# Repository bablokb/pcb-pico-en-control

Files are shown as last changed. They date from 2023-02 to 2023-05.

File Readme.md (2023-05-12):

Pico EN Control
===============

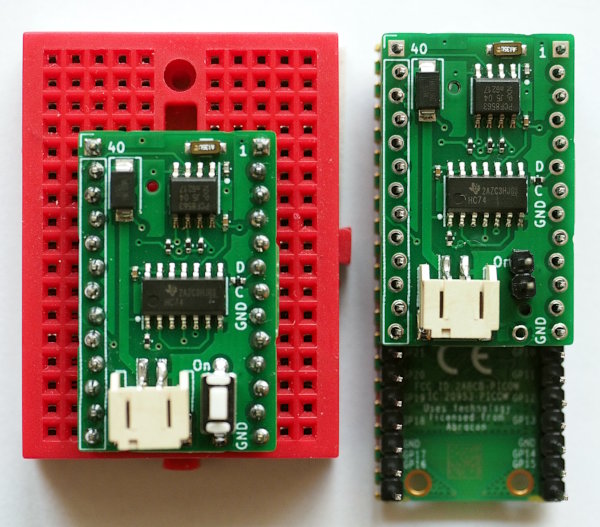
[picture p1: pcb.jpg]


This is a simple breakout to control the enable pin of a Pico to
minimize battery usage.

Functions:
  * Enable using a button, a RTC or an external signal
  * Disable by pulling a GPIO high from your program
  * keep time

The target application of this design is a program that runs in
intervals. After startup the program executes it's tasks, sets
the next wakup time and then pulls the "done"-GPIO high.
The circuitry then pulls the enable-pin low, thus limiting the
battery consumption to a very low level.

The design of the breakout allows it to be connected directly on the bottom
side of the pico. Note that the breakout uses a solderless layout for the
pins, i.e. it will hold by friction. But don't expect miracles, it may
or may not work depending on your pins. For production use, you should
definitely solder the breakout.

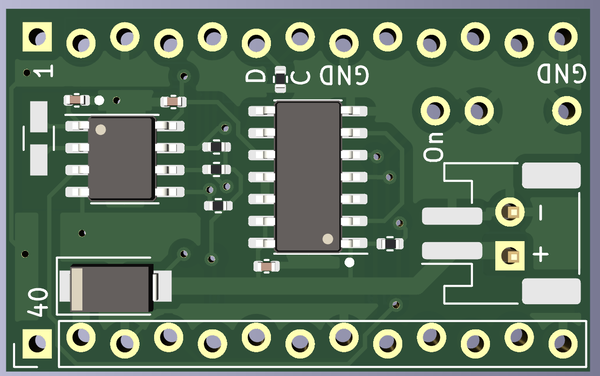
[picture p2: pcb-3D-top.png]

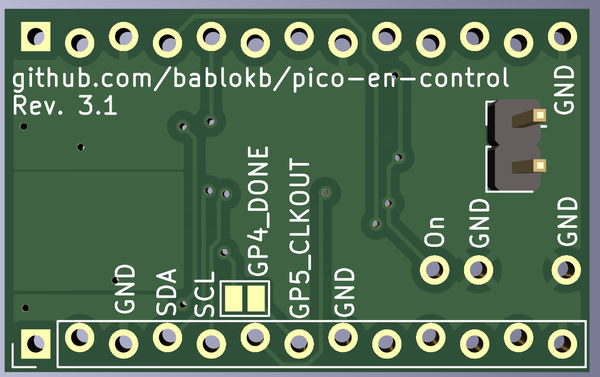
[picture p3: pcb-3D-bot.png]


Hardware Components
-------------------

A D-type flip-flop drives the enable pin of the Pico. A
button, the RTC or an external signal will reset the flip-flop,
which pulls the enable pin high.

The "done"-pin of the Pico is connected to the CLK-pin of
the flip-flop. A rising edge will toggle the enable pin.

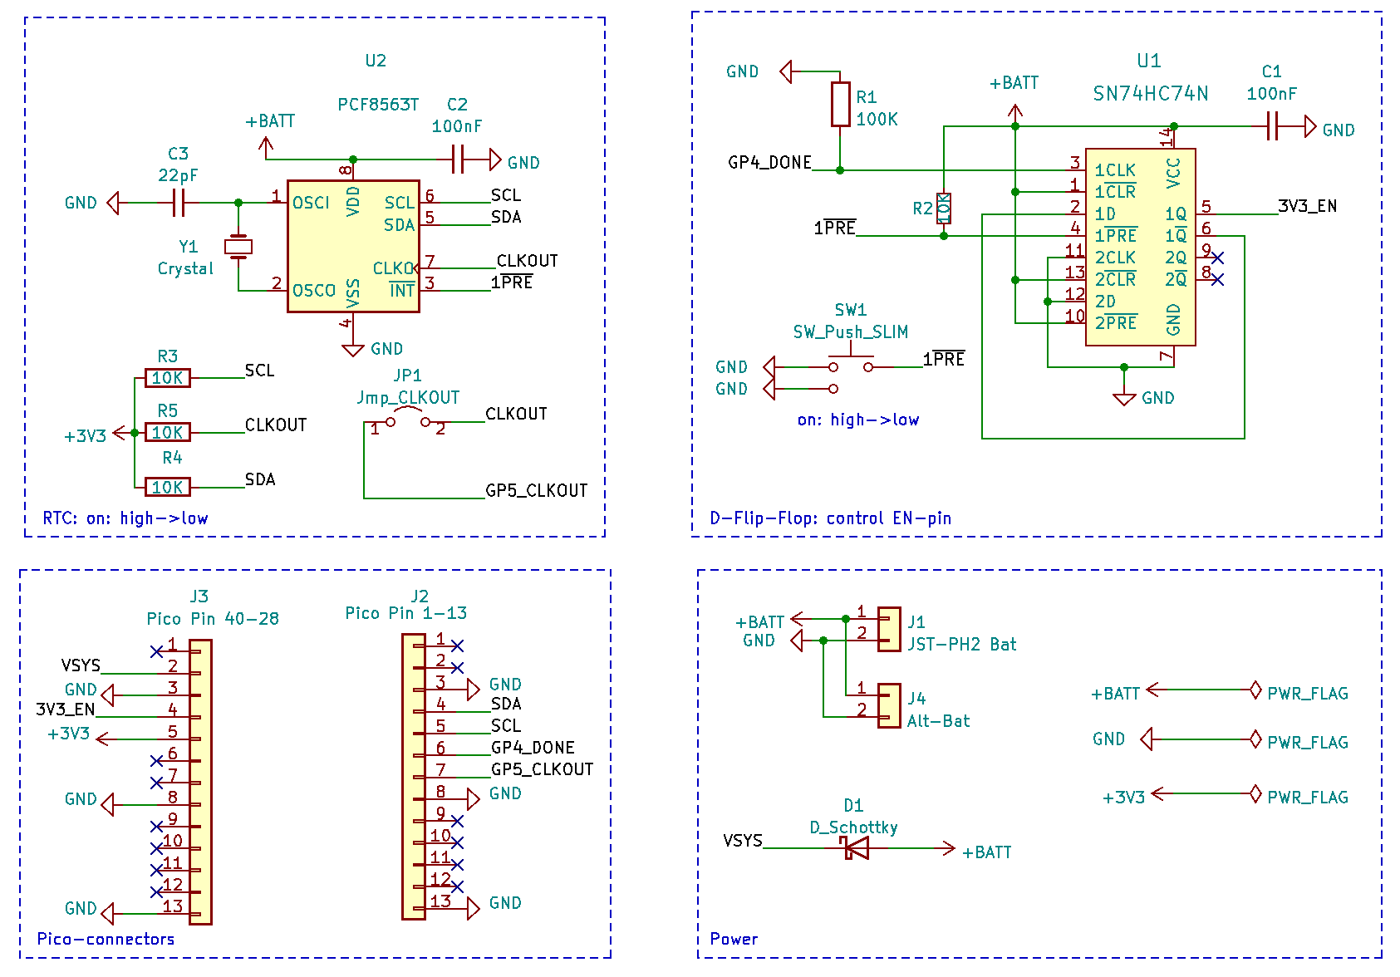
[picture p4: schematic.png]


PCB
---

PCB design files are in `pico-en-control.kicad`.

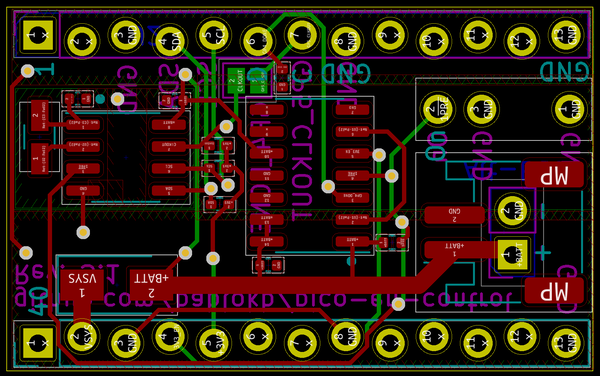
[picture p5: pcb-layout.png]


Ready to use production files for JLCPCB are in `production_files`.

Software
--------

A simple example program implemented in CircuitPython
is provided in `src/main.py`. The software provides some boilerplate
code for timer and alarm-based wake up.

In timer-mode, the program uses the countdown-timer of the rtc. It
blinks the on-board LED for ten seconds, then goes to sleep for 15 seconds.

Measured current:

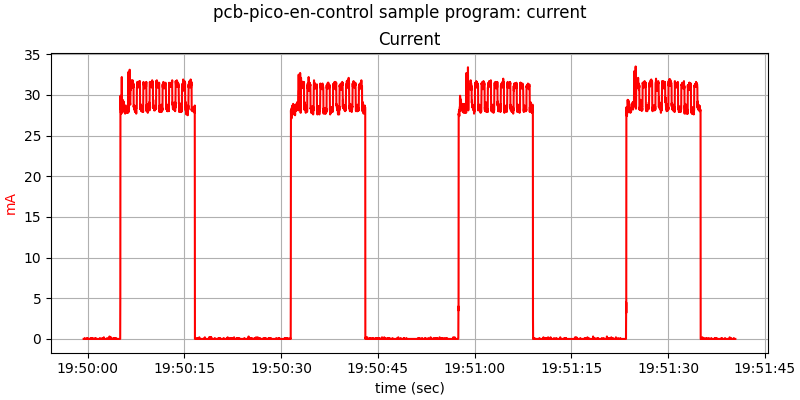
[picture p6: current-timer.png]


For longer intervals alarm-based wake up is more suitable. Since the rtc
does not support seconds for alarms, it will always fire on "full minutes".
The current measurement demonstrates this behavior (the first off-interval
is shorter than the following off-intervals):

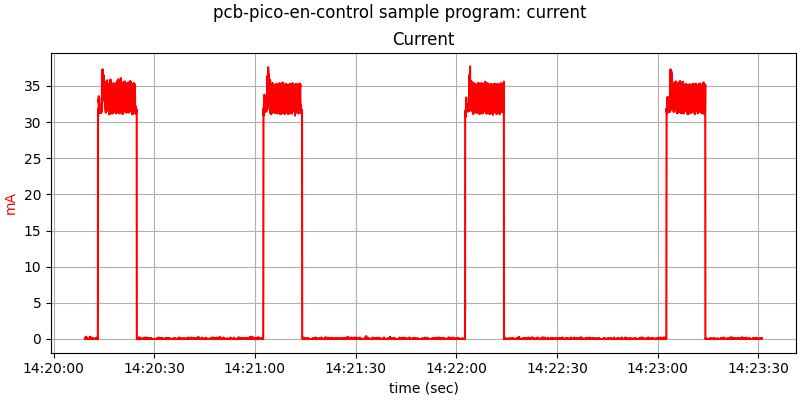
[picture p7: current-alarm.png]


Current in off-state is about 75µA (with CLKOUT disabled):

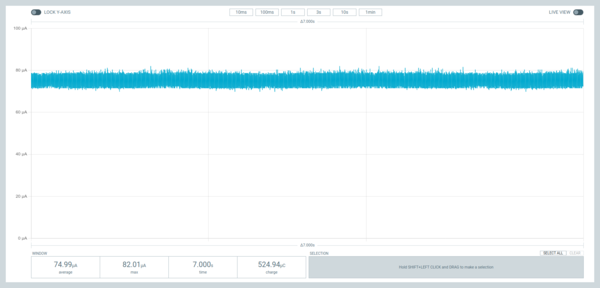
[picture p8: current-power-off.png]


License
-------

[![CC BY-SA 4.0][cc-by-sa-shield]][cc-by-sa]

This work is licensed under a
[Creative Commons Attribution-ShareAlike 4.0 International
License][cc-by-sa].

[][cc-by-sa]

[cc-by-sa]: http://creativecommons.org/licenses/by-sa/4.0/
[cc-by-sa-image]: https://licensebuttons.net/l/by-sa/4.0/88x31.png
[cc-by-sa-shield]:
https://img.shields.io/badge/License-CC%20BY--SA%204.0-lightgrey.svg

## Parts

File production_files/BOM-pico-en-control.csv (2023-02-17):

Comment | Designator | Footprint | LCSC
100nF | C1,C2 | C_0402_1005Metric | C1525
22pF | C3 | C_0402_1005Metric | C1555
D_Schottky | D1 | D_SMA | C2480
100K | R1 | R_0402_1005Metric | C25741
10K | R2,R3,R4,R5 | R_0402_1005Metric | C25744
Crystal | Y1 | Crystal_SMD_3215-2Pin_3.2x1.5mm | C32346
SN74HC74N | U1 | SOIC-14_3.9x8.7mm_P1.27mm | C6762
PCF8563T | U2 | SOIC-8_3.9x4.9mm_P1.27mm | C7440
Jmp_CLKOUT | JP1 | SolderJumper-2_P1.3mm_Open_Pad1.0x1.5mm

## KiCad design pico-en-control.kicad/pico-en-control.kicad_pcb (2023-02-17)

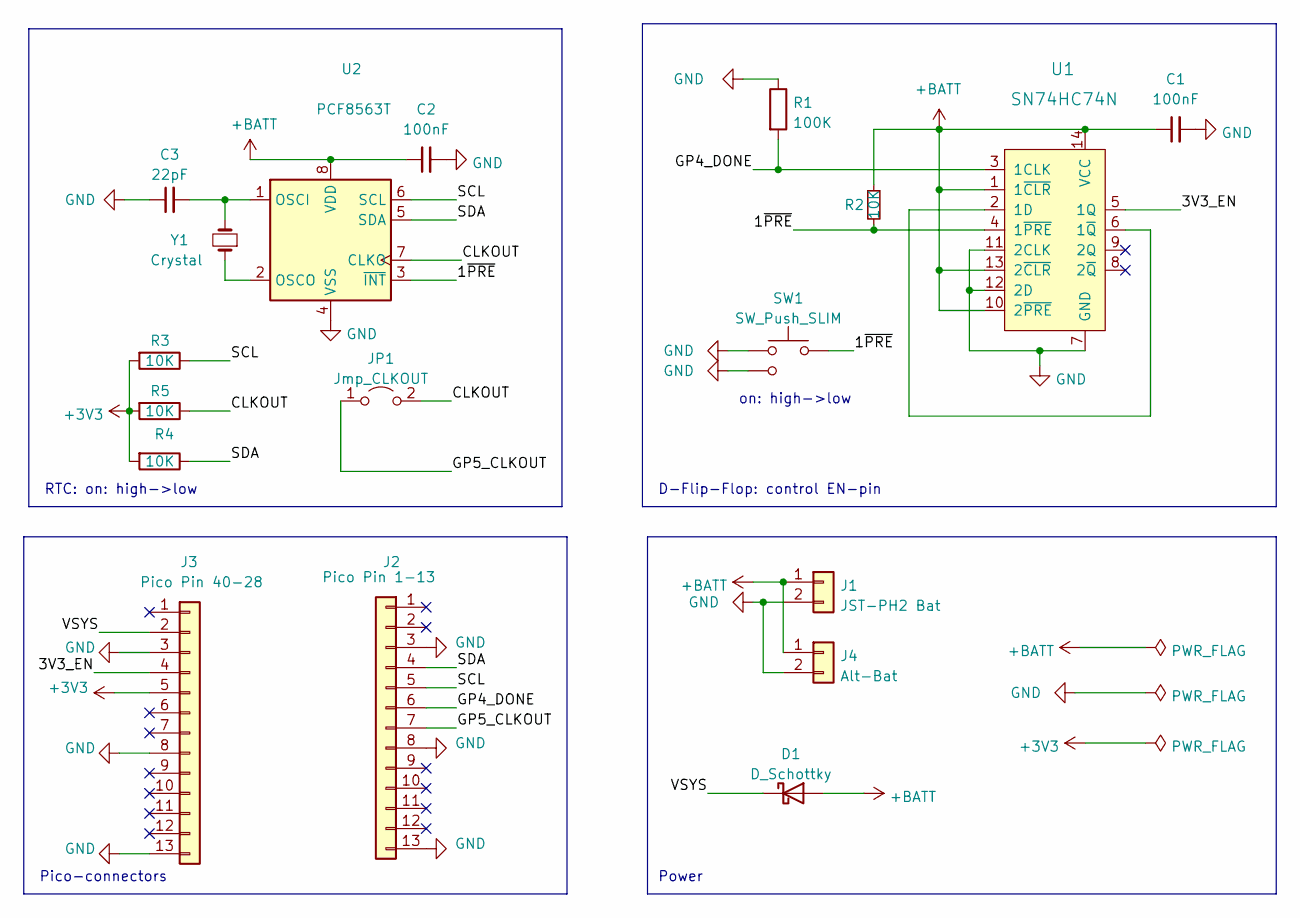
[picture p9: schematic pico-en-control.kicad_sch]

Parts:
C1, C2: 100nF; C_0402_1005Metric; LCSC C1525
C3: 22pF; C_0402_1005Metric; LCSC C1555
D1: D_Schottky; D_SMA; LCSC C2480
J1: JST-PH2 Bat; JST_PH_S2B-PH-SM4-TB_1x02-1MP_P2.00mm_Horizontal
J2: Pico Pin 1-13; Connector_1x13_no_solder
J3: Pico Pin 40-28; Connector_1x13_no_solder
J4: Alt-Bat; PinHeader_1x02_P2.54mm_Vertical
JP1: Jmp_CLKOUT; SolderJumper-2_P1.3mm_Open_Pad1.0x1.5mm
R1: 100K; R_0402_1005Metric; LCSC C25741
R2, R3, R4, R5: 10K; R_0402_1005Metric; LCSC C25744
SW1: SW_Push_SLIM; SW_PUSH_SLIM_1x4
U1: SN74HC74N; SOIC-14_3.9x8.7mm_P1.27mm; MPN SN74HC74N; Digi-Key_PN 296-1602-5-ND
U2: PCF8563T; SOIC-8_3.9x4.9mm_P1.27mm; LCSC C7440
Y1: Crystal; Crystal_SMD_3215-2Pin_3.2x1.5mm; LCSC C32346

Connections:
+3V3: J3.5, R3.2, R4.2, R5.2
+BATT: C1.1, C2.1, D1.2 (A), J1.1, J4.1, R2.1, U1.1 (1~CLR), U1.10 (2~PRE), U1.13 (2~CLR), U1.14 (VCC), U2.8 (VDD)
/1~PRE: R2.2, SW1.2, U1.4 (1~PRE), U2.3 (~INT)
/3V3_EN: J3.4, U1.5 (1Q)
/CLKOUT: JP1.2 (B), R5.1, U2.7 (CLKO)
/GP4_DONE: J2.6, R1.2, U1.3 (1CLK)
/GP5_CLKOUT: J2.7, JP1.1 (A)
/SCL: J2.5, R3.1, U2.6 (SCL)
/SDA: J2.4, R4.1, U2.5 (SDA)
/VSYS: D1.1 (K), J3.2
GND: C1.2, C2.2, C3.1, J1.2, J2.3, J2.8, J2.13, J3.3, J3.8, J3.13, J4.2, R1.1, SW1.1, SW1.3 (1), U1.7 (GND), U1.11 (2CLK), U1.12 (2D), U2.4 (VSS)
unnamed: C3.2, U2.1 (OSCI), Y1.2
unnamed: U1.2 (1D), U1.6 (1~Q)
unnamed: U2.2 (OSCO), Y1.1

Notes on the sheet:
Power
D-Flip-Flop: control EN-pin
Pico-connectors
RTC: on: high->low
on: high->low

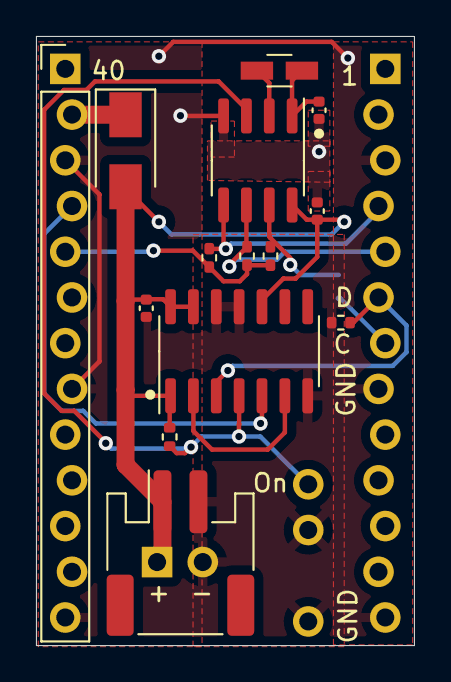
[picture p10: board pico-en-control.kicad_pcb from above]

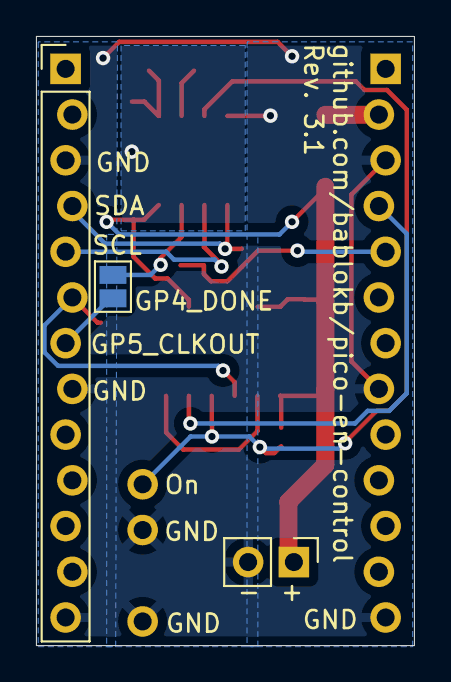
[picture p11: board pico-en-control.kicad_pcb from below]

Board: 2 copper layers, 21.0 x 33.8 mm, 18 parts (3 on the bottom side), 14 nets.

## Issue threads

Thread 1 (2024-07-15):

Can you please add a version for esp32-wroom-32?

mosheliv, 2024-07-15:
They are just much cheaper and for any practical purpose just as good for sensors.

bablokb, 2024-07-15:
The ESP32-WROOM-32 is an old chip not recommended for newer designs. And "much" cheaper is something I would not agree with. The chip itself is much cheaper, but the difference in dev-board prices is not that high. Especially if you don't buy the cheapest stuff you can find on Ali.

BTW: you can use the existing PCB with any 3V3 MCU. You cannot just plug it into the device.

mosheliv, 2024-07-15:
I am trying to use this to have a sensor monitoring soil moisture of a
plant once a day. As I'm thinking about 10+ sensors, the difference between
the cheap esp32 and the pico is substantial. Yes, i did realize i could use
it independently (and will, already ordered a few from jlbpcb, thank you
for making it so easy) but no harm in asking...
Cheap Esp32 is about 2.5$, pico wifi is about 10$.
Best regards and many thanks for the work you did!

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

bablokb, 2024-07-15:
Yes, no problem. Designing it for a specific ESP32 breakout would not be much work, but I would have to know the exact pinout, have a sample dev-board and so on. But I am busy with other projects...

What I might do one day is redesign the board to be a bit more generic designed for wiring. I.e. with a single connector, all necessary pins on one side.

mosheliv, 2024-07-15:
I think the most common amature board is the esp32-cam. It is very cheap
and reasonably powerful and has an okish camera and all for around $5.
However, it is notoriously bad as a battery operated device as it draws a
lot of current when idle/deep sleep and needs regulated voltage (thats the
greatest thing about your board - the regulator can be after the board!). i
will make some tests with the boards when the arrive and see if it works as
advertised on a breadboard.

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

mosheliv, 2024-07-19:
Another question (and forgive me if its stupid as I'm a complete amature) :
why did you choose the enable pin and not a more general solution using
a IRLZ44N MOSFET to turn on the chip from zero? This should be even more
energy efficient, no?

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

bablokb, 2024-07-19:
A valid question and I already have an alternative board for that: https://github.com/bablokb/pcb-pico-power-switch

Indeed, the regulator inside the Pico will draw about 75µA even when EN is pulled low. So my other board is more efficient (I measured something like 350nA in off-mode). Since the second board also uses a mosfet for reverse-power protection (instead of a schottky), the voltage drop is also lower.

But there is a use-case where this board is better: driving the EN pin also works when on USB-power. Also, you will find DC-DC converters with EN-pin, so you can also drive the power-source.

mosheliv, 2024-07-19:
Ohhhh I wish i saw this before! Amazing, sent it to jlpcb...
Thank you AGAIN for making it so easy.
I saw that there is an esp32-c3. It's tiny but reasonably strong, very very
low power even when working and dirt cheap as smt component as it's risc v
so no amd royalties. It has limited io but for a single sensor it will do
nicely.
Was thinking of making the whole circuit (the one with the MOSFET) with the
processor on board but this is still far beyond my very basic abilities as
it needs antenna and other black magic stuff like voltage regulator. Will
give it a go anyways, perhaps will learn something while trying.

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

bablokb, 2024-07-19:
Antennas are complicated and the regulator-stuff is also difficult. I am using the QT-Py ESP32-C3 from Adafruit, and the antenna they added really had problems. I removed the on-board antenna which just did not work and added an external one. This only shows how complicated things are.

Voltage regulators are also challenging. You can spoil everything here. I have an ESP32-S3 board from Adafruit which uses 18µA in deep-sleep, and an ESP32-S3 board from Waveshare which uses 1000µA.

mosheliv, 2024-07-19:
Yes, the cheap esp32 are pretty horrible in deep sleep, hence my joy at
finding your circuit.... I ordered c3 super mini to check its deep sleep
current. If I can get the boards to work, I'll have under 10$ per node
moisture sensor and pir light/detection with wifi that are supposed to work
for years before battery needs to be changed and i can use 18650 because
the voltage regulator is after the mosfet. Hopefully everything will work
well.

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

Closed 2024-07-15.

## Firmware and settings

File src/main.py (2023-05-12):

#-----------------------------------------------------------------------------
# Test program.
#
# The program supports two modes:
#
# timer-mode: blink the onboard LED for 10 seconds, then goe to sleep
#             and wakes up again after 15 seconds.
#
# alarm-mode: blink the onboard LED for 10 seconds, then goe to sleep
#             and wake up at the start of the next minute
#
# The countdown-timer of the RTC and works on a PCF8563 up to
# 15300 seconds (i.e. 255m or 4h15m). For longer intervals than
# 255 minutes use the alarm or switch to the PCF8523.
#
# Author: Bernhard Bablok
#
# Website: https://github.com/pcb-pico-en-control
#-----------------------------------------------------------------------------

OFF_MODE_TIMER = 0      # 0: use alarm, 1: use timer

import time
import board
import alarm
from digitalio import DigitalInOut, Direction, Pull

# imports for PCF8563
import busio
if OFF_MODE_TIMER:
  from adafruit_pcf8563.timer import Timer as PCF_RTC
else:
  from adafruit_pcf8563.pcf8563 import PCF8563 as PCF_RTC

# --- configuration   --------------------------------------------------------

PIN_DONE = board.GP4   # connect to 74HC74 CLK
PIN_SDA  = board.GP2   # connect to RTC
PIN_SCL  = board.GP3   # connect to RTC

LED_TIME = 0.5         # blink-duration
ON_TIME  = 10          # seconds on (blinking)
OFF_TIMER = 15         # seconds off (<= 15300 == 255*60)
OFF_ALARM = 1          # wake up in x minutes

# --- create hardware objects   ----------------------------------------------

led            = DigitalInOut(board.LED)
led.direction  = Direction.OUTPUT

done           = DigitalInOut(PIN_DONE)
done.direction = Direction.OUTPUT
done.value     = 0

i2c = busio.I2C(PIN_SCL,PIN_SDA)
rtc = PCF_RTC(i2c)

# --- simulate work   --------------------------------------------------------

def blink(dur=LED_TIME,repeat=1):
  while repeat:
    led.value = 1
    time.sleep(dur)
    led.value = 0
    time.sleep(dur)
    repeat -= 1

# --- set timer   ------------------------------------------------------------

def set_timer(secs):
  if secs < 256:
    rtc.timer_frequency = rtc.TIMER_FREQ_1HZ
    rtc.timer_value = secs
  else:
    rtc.timer_frequency = rtc.TIMER_FREQ_1_60HZ
    rtc.timer_value = min(255,int(secs/60)+1)
  
  # enable timer and interrupt
  rtc.timer_interrupt = True
  rtc.timer_enabled   = True

# --- set alarm   ------------------------------------------------------------

def set_alarm(minutes):
  alarm_time = time.mktime(rtc.datetime) + 60*minutes
  rtc.alarm  = (time.localtime(alarm_time),"daily")
  rtc.alarm_interrupt = True

# --- main program   ---------------------------------------------------------

# disable timer interrupt and clear timer/alarm
if OFF_MODE_TIMER:
  rtc.timer_status    = False
  rtc.timer_pulsed    = False
  rtc.timer_interrupt = False
  rtc.timer_enabled   = False
else:
  rtc.alarm_status     = False
  rtc.alarm_interrupt  = False
  rtc.clockout_enabled = False
  if rtc.lost_power:
    rtc.datetime =time.struct_time((2022,10,3,13,5,12,0,277,-1))

# Simulate some work by blinking the LED
active_until = time.monotonic() + ON_TIME
print("working...")
while time.monotonic() < active_until:
  blink()

# finished working, set timer or alarm and exit
if OFF_MODE_TIMER:
  set_timer(OFF_TIMER)
else:
  set_alarm(OFF_ALARM)

done.value = 1 # signal "done" to external circuit - this should turn us off
time.sleep(0.2)
done.value = 0
time.sleep(0.5)

# this won't happen (it should not)
blink(LED_TIME/3,4)
time.sleep(2)

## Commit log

2023-02-02 draft routing
    [pico-en-control.kicad_pcb, pico-en-control.kicad_sch]
2023-02-03 switched to 13-pin connectors
    [pico-en-control.kicad_pcb, pico-en-control.kicad_sch]
2023-02-03 DRC ok
    [pico-en-control.kicad_pcb, pico-en-control.kicad_sch]
2023-02-17 Rev 3.1 (prod)
    [BOM-pico-en-control.csv, pico-en-control.kicad_pcb, pico-en-control.kicad_sch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]
2023-03-02 updated with details about the PCB and the sample program
2023-03-06 renamed file current.png -> current-timer.png
2023-05-12 added link to power-off graphics
2023-05-12 update for new measurement with 75µA current in off-state
